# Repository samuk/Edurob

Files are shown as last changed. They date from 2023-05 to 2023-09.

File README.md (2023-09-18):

# EduRob
[Homepage](https://www.imsl.fh-dortmund.de/mobile-roboter/edurob/)
## Educational robot with support for various drive kinematics

EduRob is a handy mobile robot specially designed for education. Through clever design, it is possible to cover different types of drives such as Mecanum, Omniwheel, and differential drive.



## Detailed information:

[Getting Started](Doc/README.md)

[Partslist](Doc/Partslist/README.md)

[PCB](PCB/README.md) 

[CAD](CAD/README.md) 

## Example projects:

[SLAM](Projects/SLAM/README.md)

[Line Follower](https://github.com/blssed/EduRob-LineFollower)

---

## Background

In the robotics lab, there is a wide range of different robots available for use in teaching and for the completion of thesis projects. However, they all share one major disadvantage: they prefer to drive themselves rather than being carried. As a result, their application is limited to the lab itself and adjacent rooms.

Especially for basic training in mobile robotics such as controlling different types of drives (Mecanum, Omniwheel, or differential drive), implementing control tasks, and connecting sensors, the experimental area of the robotics lab is not necessarily required. This led to the requirement of developing a flexible platform that can cover all types of drives, and small enough to be taken in a backpack to the home office.

# Possible configurations

EduRob can be equipped with three or four motors and different types of wheels. The motors can be flexibly reconnected by loosening two screws, and other wheels can be attached to the motor shaft.

## Mecanum 

With four motors at the four outer corners, EduRob can be turned into a robot with a classic Mecanum drive. The driving behavior is thus similar to that of OmniMan and the other Mecanum robots of the IMSL.



## Omniwheel with three wheels (120°)

With three motors, EduRob can simulate the classic omniwheel configuration. Three wheels rotated by 120° each allow for omnidirectional driving behavior.



## Omniwheel with four wheels (90°)

In addition to the classic arrangement with three omniwheels, EduRob can also simulate the special form with four omniwheels. Here, four omniwheels are arranged with a rotation of 90° to each other. In comparison to the Mecanum arrangement, the wheels are rotated by about 45°. In this configuration, EduRob can also be driven omnidirectionally.



## Differential drive or Skid-Steer drive

The driving behavior of the Pioneer robots in the IMSL inventory is made possible by the use of four wheels. Even though the arrangement of the wheels is similar to the Mecanum arrangement, sideways movement is not possible due to the use of classic wheels without freewheeling rollers. In addition to forward and backward movement and rotation around the center of the platform, driving in circular arcs is possible. This type of drive is also called Skid-Steer drive. Due to the 4x4 drive, this configuration is particularly suitable for rough terrain. The absence of freewheeling rollers on the wheels also means they are less likely to become contaminated or blocked.



By using two classic wheels and one or two non-driven Omniwheels, a proper differential drive is also possible. In this case, the rotation point moves to the midpoint between the two driven wheels. While this affects the robot's turning behavior (the front part swings out), it still maintains its limited range of movement (forward, backward, turning, and driving in circles). However, the "off-road" capability is reduced by the reduction to two driven wheels, and the use of Omniwheels increases the risk of contamination of free-rolling rollers.



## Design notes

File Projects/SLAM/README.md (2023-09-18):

# EduRob SLAM
[Homepage](https://www.imsl.fh-dortmund.de/mobile-roboter/edurob/)
## Project files for SLAM with EduRob

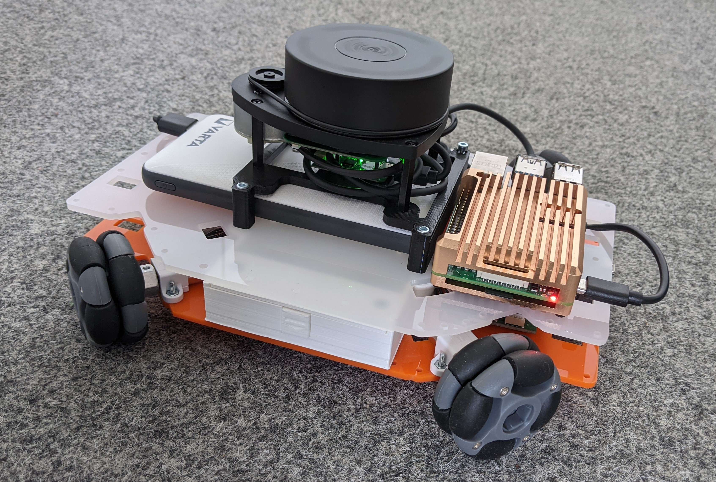
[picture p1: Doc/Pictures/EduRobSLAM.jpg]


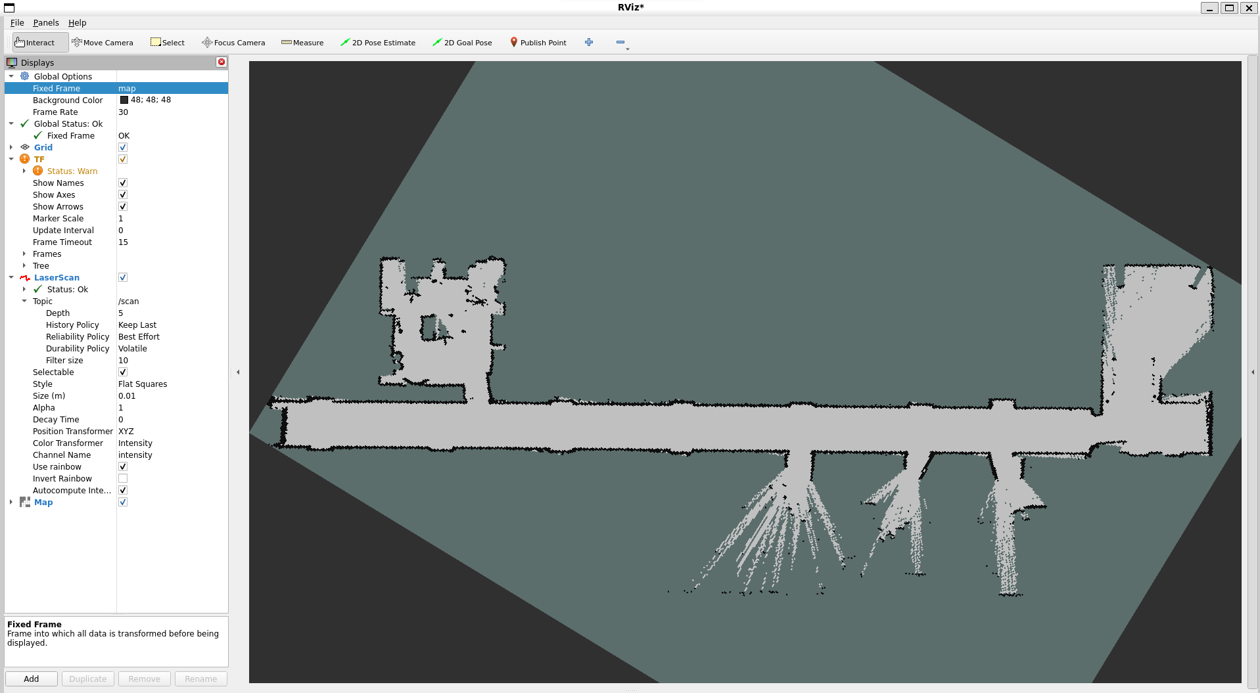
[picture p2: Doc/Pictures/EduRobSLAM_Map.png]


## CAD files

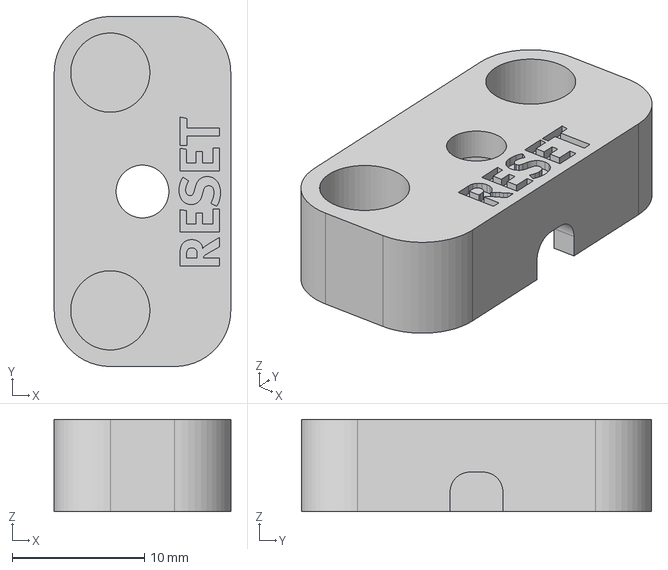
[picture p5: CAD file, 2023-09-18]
CAD/EduRob_Reset_Button_Holder.step
13.4 x 26.5 x 7.00 mm

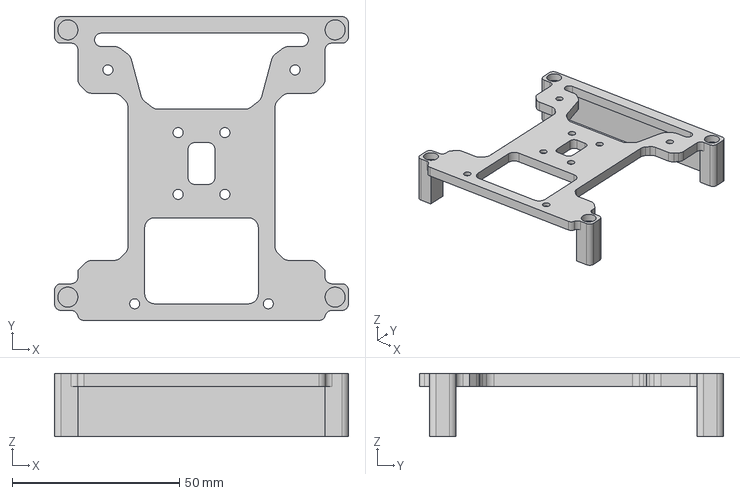
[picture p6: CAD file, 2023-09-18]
Projects/SLAM/LIDAR_Adapter v5.step
88.0 x 91.0 x 19.0 mm

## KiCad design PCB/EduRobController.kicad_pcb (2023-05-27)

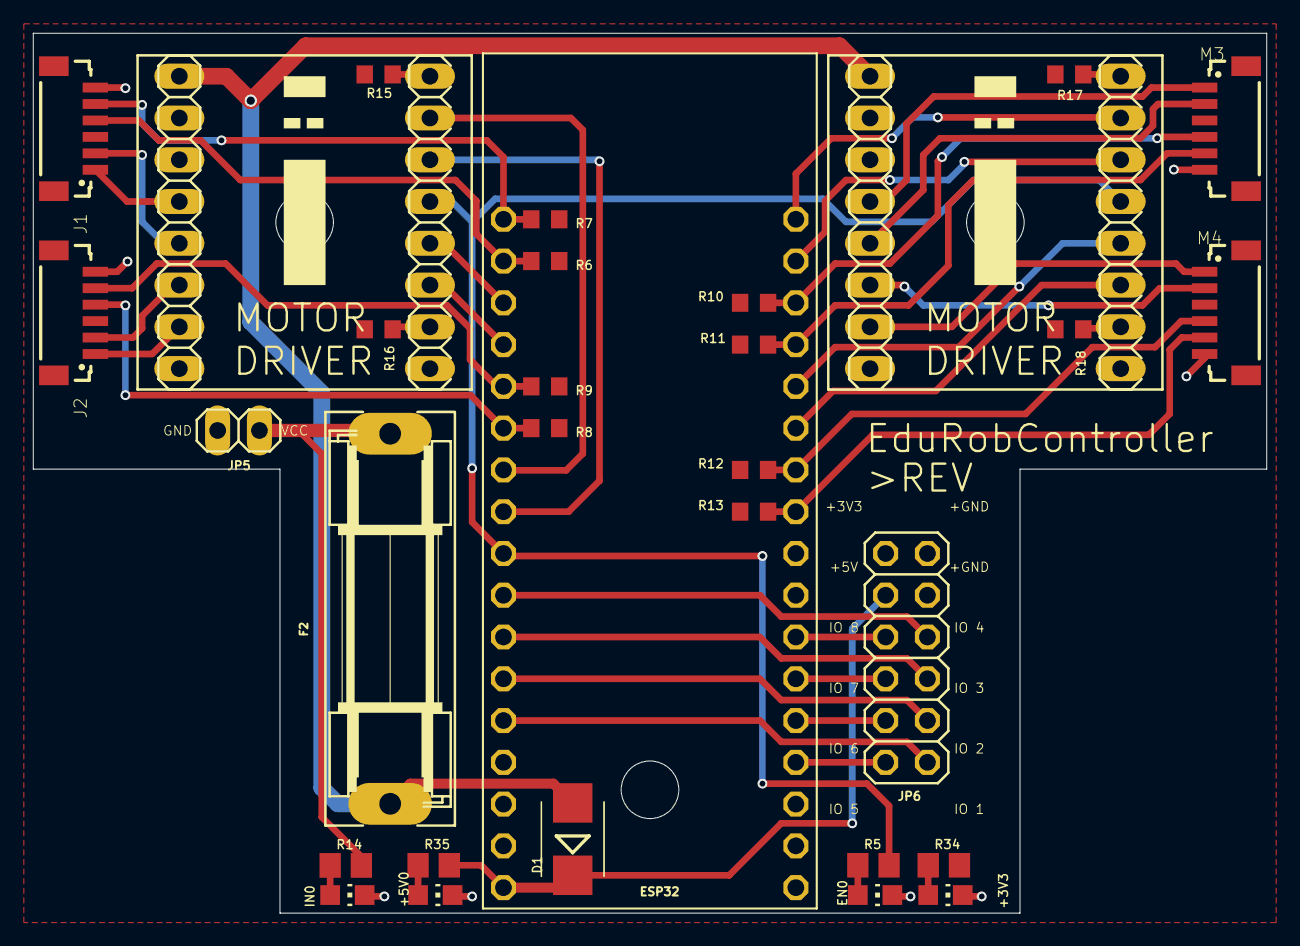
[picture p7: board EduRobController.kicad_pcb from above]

Board: 2 copper layers, 75.0 x 53.5 mm, 34 parts (0 on the bottom side), 46 nets.

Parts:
+3V3, +5V0: CHIP-LED0805
@HOLE0, @HOLE1, @HOLE2: (no value)
D1: SMB
EN0: CHIP-LED0805
F2: 534-4628; SH22,5
IN0: CHIP-LED0805
J1, J2: 665306124022
JP5: 1X02
JP6: 2X06
M3, M4: 665306124022
R5, R14, R34, R35: R0805
R6, R7, R8, R9, R10, R11, R12, R13, R15, R16, R17, R18: R0603
U$1: ESP32
U$2, U$3: TB6612FNG; 2X08

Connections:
+3V3: J1.3, J2.3, JP6.12, M3.3, M4.3, R6.2, R7.2, R8.2, R9.2, R10.2, R11.2, R12.2, R13.2, R15.2, R16.2, R17.2, R18.2, R34.2, U$1.3V3, U$1.3V3., U$2.7, U$3.7
+5V: D1.C, JP6.10, R35.2, U$1.5V
ENM: R5.2, U$1.12, U$2.13, U$3.13
GND: +3V3.C, +5V0.C, EN0.C, IN0.C, J1.6, J2.6, JP5.2, JP6.9, JP6.11, M3.6, M4.6, U$1.GND, U$1.GND., U$2.1, U$2.6, U$2.9, U$3.1, U$3.6, U$3.9
GPIO1: JP6.1, U$1.4
GPIO2: JP6.3, U$1.2
GPIO3: JP6.5, U$1.15
GPIO4: JP6.7, U$1.13
GPIO5: JP6.2, U$1.37
GPIO6: JP6.4, U$1.38
GPIO7: JP6.6, U$1.34
GPIO8: JP6.8, U$1.35
M1A: J1.1, U$2.5
M1B: J1.2, U$2.4
M1ENCA: J1.4, R6.1, U$1.VN
M1ENCB: J1.5, R7.1, U$1.VP
M1PWMA: U$1.14, U$2.14
M1PWMB: U$1.27, U$2.15
M2A: J2.1, U$2.2
M2B: J2.2, U$2.3
M2ENCA: J2.4, R8.1, U$1.33
M2ENCB: J2.5, R9.1, U$1.32
M2PWMA: U$1.25, U$2.12
M2PWMB: U$1.26, U$2.11
M3A: M3.1, U$3.5
M3B: M3.2, U$3.4
M3ENCA: M3.4, R10.1, U$1.19
M3ENCB: M3.5, R11.1, U$1.23
M3PWMA: U$1.22, U$3.14
M3PWMB: U$1.21, U$3.15
M4A: M4.1, U$3.2
M4B: M4.2, U$3.3
M4ENCA: M4.4, R12.1, U$1.10
M4ENCB: M4.5, R13.1, U$1.9
M4PWMA: U$1.18, U$3.12
M4PWMB: U$1.5, U$3.11
unnamed: +3V3.A, R34.1
unnamed: +5V0.A, R35.1
unnamed: EN0.A, R5.1
unnamed: IN0.A, R14.1
unnamed: R17.1, U$3.16
unnamed: R18.1, U$3.10
unnamed: R15.1, U$2.16
unnamed: R16.1, U$2.10
VCC: F2.1, JP5.1, R14.2
VDD: D1.A, F2.2, U$2.8, U$3.8

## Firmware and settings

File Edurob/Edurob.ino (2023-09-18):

#define ROS_EN
// #define ROS_CON_WIFI // Use WIFI instead of Serial (USB)

// #define MECANUM
// #define DIFF
#define OMNI4
// #define OMNI3

#ifdef ROS_EN
#define RCCHECK(fn)              \
  {                              \
    rcl_ret_t temp_rc = fn;      \
    if ((temp_rc != RCL_RET_OK)) \
    {                            \
      error_loop();              \
    }                            \
  }
#define RCSOFTCHECK(fn)          \
  {                              \
    rcl_ret_t temp_rc = fn;      \
    if ((temp_rc != RCL_RET_OK)) \
    {                            \
    }                            \
  }
#endif // ROS_EN

#include <WiFi.h>
#include "sdkconfig.h"
#include "esp_system.h"
#include "freertos/FreeRTOS.h"
#include "freertos/task.h"
#include "freertos/timers.h"
#include "freertos/event_groups.h"
#include "math.h"

#include <dcpwm.h>       // PWM
#include <ESP_Counter.h> // Encoder
#include <AutoPID.h>     // PID Library https://github.com/r-downing/AutoPID
#include <Eigen.h>       // Linear math
#include <Eigen/QR>      // Calls inverse, determinant, LU decomp., etc.
using namespace Eigen;   // Eigen related statement; simplifies syntax for declaration of matrices

#ifdef ROS_EN
// ROS
#include <micro_ros_arduino.h>
#include <stdio.h>
#include <rcl/rcl.h>
#include <rcl/error_handling.h>
#include <rclc/rclc.h>
#include <rclc/executor.h>
#include <micro_ros_utilities/type_utilities.h>
#include <micro_ros_utilities/string_utilities.h>

// ROS Messages
#include <geometry_msgs/msg/twist.h>
#include <geometry_msgs/msg/transform_stamped.h>
#include <tf2_msgs/msg/tf_message.h>
#include <custom_message/msg/speed.h>
#endif ROS_EN

// Project specific headers
#include "parameter.h"

// Hardware
static ESP_Counter WheelEncoder[NumMotors];      // Hardware-Encoder-Units
static DCPWM MotorPWM[NumMotors];                // Hardware-PWM-Units
static AutoPID *speedController[NumMotors];      // PID-Units
static pidParam speedControllerParam[NumMotors]; // PID-Parameter

// Variables
int64_t encoderOld[NumMotors];       // Last encoder values
int64_t encoderNew[NumMotors];       // Current encoder values
const int windowSize = 5;            // Number of values in moving average window
float inputs[NumMotors][windowSize]; // Input values for moving average
float inputsum[NumMotors];           // Sum of values for moving average
int windowIndex = 0;                 // Currently accessed cell of inputs[motornum][x];

// Setpoints
static double setpointSpeed[NumMotors]; // Motorspeed setpoints

// Matrix
MatrixXd kinematik(4, 3);    // Kinematics matrix for differential
MatrixXd kinematikInv(3, 4); // Inverse Kinematics matrix for differential
Vector3d robotSpeedSetpoint; // Vector with translationional and rotational robot speeds in m/s and rad/s  (X(m/s), Y(m/s), Z(rad/s))
Vector3d robotSpeed;         // Vector with translationional and rotational robot speeds in m/s and rad/s  (X(m/s), Y(m/s), Z(rad/s))
Vector3d robotSpeedMax;      // Vector with translationional and rotational robot speeds in m/s and rad/s  (X(m/s), Y(m/s), Z(rad/s))
Vector3d robotSpeedAcc;      // Vector with translationional and rotational robot speeds in m/s and rad/s  (X(m/s), Y(m/s), Z(rad/s))
Vector4d wheelSpeedSetpoint; // Wheel speeds in rad/s
Vector3d robotOdom;          // Odometry Position
Vector4d robotWheelSpeed;    // Current wheel speeds
Vector3d robotOdomSpeed;     // Odometry Speed
double rosQuaternion[4];     // Quaternion for ROS transform message

#ifdef ROS_EN
// ROS
rclc_support_t support;
rcl_allocator_t allocator;
rclc_executor_t executor;
rcl_node_t node;

geometry_msgs__msg__TransformStamped tfData[3];
geometry_msgs__msg__TransformStamped tfStaticData[3];
int32_t speedData[4];
rcl_subscription_t twistSubscriber;
geometry_msgs__msg__Twist twistMessage;

tf2_msgs__msg__TFMessage messageTf;
rcl_publisher_t publisherTf;
tf2_msgs__msg__TFMessage messageTfStatic;
rcl_publisher_t publisherTfStatic;
custom_message__msg__Speed messageSpeed;
rcl_publisher_t publisherSpeed;
#endif // ROS_EN

// Error function in case of unhandeld ros-error
void error_loop()
{
  while (1)
  {
    Serial.println("ERR");
    delay(100);
  }
}

// Convert Eulerdegrees to quaternion
const void euler_to_quat(float x, float y, float z, double *q)
{
  float c1 = cos(y / 2.0);
  float c2 = cos(z / 2.0);
  float c3 = cos(x / 2.0);

  float s1 = sin(y / 2.0);
  float s2 = sin(z / 2.0);
  float s3 = sin(x / 2.0);

  q[0] = c1 * c2 * c3 - s1 * s2 * s3;
  q[1] = s1 * s2 * c3 + c1 * c2 * s3;
  q[2] = s1 * c2 * c3 + c1 * s2 * s3;
  q[3] = c1 * s2 * c3 - s1 * c2 * s3;
}

// Rotate 2D-Vector
const void rotate2D(float r, double &x, double &y)
{
  double temp = x * cos(r) - y * sin(r);
  y = x * sin(r) + y * cos(r);
  x = temp;
}

// Twist message cb
void subscription_callback(const void *msgin)
{
  const geometry_msgs__msg__Twist *msga = (const geometry_msgs__msg__Twist *)msgin;
  robotSpeedSetpoint << msga->linear.x, msga->linear.y, msga->angular.z;
}

// Print content of Eigen::MatrixXd
void print_mtxd(const Eigen::MatrixXd &X)
{
  int i, j, nrow, ncol;

  nrow = X.rows();
  ncol = X.cols();

  Serial.print("nrow: ");
  Serial.println(nrow);
  Serial.print("ncol: ");
  Serial.println(ncol);
  Serial.println();

  for (i = 0; i < nrow; i++)
  {
    for (j = 0; j < ncol; j++)
    {
      Serial.print(X(i, j), 6); // print 6 decimal places
      Serial.print(", ");
    }
    Serial.println();
  }
  Serial.println();
}

// Init Encoder- and PWM-Units
bool initHardware()
{
  pinMode(EnablePIN, OUTPUT);   // Motor enable signal
  digitalWrite(EnablePIN, LOW); // Disable motors
  for (int i = 0; i < NumMotors; i++)
  {
    if (!WheelEncoder[i].init(i, Enc_A[i], Enc_B[i]))
    {
      return false;
    }
  }

  int currentChannel = 0;
  for (int i = 0; i < NumMotors; i++)
  {
    if (!MotorPWM[i].init(30000, 10, currentChannel, currentChannel + 1, PWM_A[i], PWM_B[i]))
    {
      return false;
    }
    MotorPWM[i].setPWM(0); // Set initial speed to 0
    currentChannel += 2;
  }

  return true;
}

// Init speed controller
void initPID()
{
  for (int i = 0; i < NumMotors; i++)
  {
    speedControllerParam[i].input = 0;
    speedControllerParam[i].output = 0;
    speedControllerParam[i].setpoint = 0;
    speedControllerParam[i].p = 0.04;
    speedControllerParam[i].i = 0.08;
    speedControllerParam[i].d = 0.0;
    speedControllerParam[i].sampleTimeMs = sampleTime;
    speedControllerParam[i].outMin = -100;
    speedControllerParam[i].outMax = 100;

    speedController[i] = new AutoPID(&speedControllerParam[i].input, &speedControllerParam[i].setpoint, &speedControllerParam[i].output, speedControllerParam[i].outMin, speedControllerParam[i].outMax, speedControllerParam[i].p, speedControllerParam[i].i, speedControllerParam[i].d);
    speedController[i]->setTimeStep(speedControllerParam[i].sampleTimeMs);
    speedController[i]->setBangBang(0, 0); // Disable BangBang-Controll
  }
}

// Init platformspecific kinematics
void initMatrix()
{

#ifdef MECANUM
  // Mecanum
  kinematik << 1, 1, (l1 + l2),
      1, -1, -(l1 + l2),
      1, -1, (l1 + l2),
      1, 1, -(l1 + l2);

  kinematikInv << 1, 1, 1, 1,
      1, -1, 1, -1,
      1.0 / (l1 + l2), -1.0 / (l1 + l2), 1.0 / (l1 + l2), -1.0 / (l1 + l2);

  kinematik = 1 * kinematik;
  kinematikInv = (1 / 4.0) * kinematikInv;
#endif

#ifdef DIFF
  // Diff
  kinematik << 1, 0, l2,
      1, 0, -l2,
      1, 0, l2,
      1, 0, -l2;

  kinematikInv << 1, 1, 1, 1,
      0, 0, 0, 0,
      1.0 / l2, -1.0 / l2, 1.0 / l2, -1.0 / l2;

  kinematik = 1 * kinematik;
  kinematikInv = (1 / 4.0) * kinematikInv;
#endif

#ifdef OMNI4
  // Omni 4 Wheels
  kinematik << -(1), -(1), (sqrt(2) * 0.08305),
      -(1), (1), -(sqrt(2) * 0.08305),
      -(1), (1), (sqrt(2) * 0.08305),
      -(1), -(1), -(sqrt(2) * 0.08305);

  kinematikInv << -sqrt(2) / 2, -sqrt(2) / 2, -sqrt(2) / 2, -sqrt(2) / 2,
      -sqrt(2) / 2, sqrt(2) / 2, sqrt(2) / 2, -sqrt(2) / 2,
      1 / (2 * (sqrt(2) * 0.08305)), -1 / (2 * (sqrt(2) * 0.08305)), 1 / (2 * (sqrt(2) * 0.08305)), -1 / (2 * (sqrt(2) * 0.08305));

  kinematik = ((sqrt(2) / (2))) * kinematik;
  kinematikInv = (0.5) * kinematikInv;
#endif

  robotSpeedSetpoint << 0.0,
      0.0,
      0.0;

  robotSpeedAcc << maxTAccel, maxTAccel, maxRAccel;
  robotSpeedMax << maxTSpeed, maxTSpeed, maxRSpeed;
  wheelSpeedSetpoint = (1 / wheelRadius) * kinematik * robotSpeedSetpoint;
}

// Speed controller task
void speedControllerTask(void *pvParameters)
{
  TickType_t xLastWakeTime = xTaskGetTickCount();
  const TickType_t xFrequency = pdMS_TO_TICKS(sampleTime);

  for (int i = 0; i < NumMotors; i++)
  {
    inputsum[i] = 0;
  }

  for (int i = 0; i < NumMotors; i++)
  {
    for (int k = 0; k < windowSize; k++)
    {
      inputs[i][k] = 0;
    }
  }

  while (true)
  {
    vTaskDelayUntil(&xLastWakeTime, xFrequency);
    for (int i = 0; i < 3; i++)
    {
      if (robotSpeed[i] > robotSpeedSetpoint[i])
      {
        robotSpeed[i] = robotSpeed[i] - (robotSpeedAcc[i] * 0.005);
      }
      else if (robotSpeed[i] < robotSpeedSetpoint[i])
      {
        robotSpeed[i] = robotSpeed[i] + (robotSpeedAcc[i] * 0.005);
      }

      if (robotSpeed[i] > robotSpeedMax[i])
      {
        robotSpeed[i] = robotSpeedMax[i];
      }
      else if (robotSpeed[i] < -robotSpeedMax[i])
      {
        robotSpeed[i] = -robotSpeedMax[i];
      }
    }
    wheelSpeedSetpoint = (1 / wheelRadius) * kinematik * robotSpeed;
    for (int i = 0; i < NumMotors; i++)
    {
      if (abs(wheelSpeedSetpoint[i]) < 0.15)
      {
        wheelSpeedSetpoint[i] = 0;
      }
    }

    for (int i = 0; i < NumMotors; i++)
    {
      speedControllerParam[i].setpoint = wheelSpeedSetpoint(i, 0);
      encoderNew[i] = EncoderDir[i] * WheelEncoder[i].getCount();

      inputsum[i] -= inputs[i][windowIndex];
      inputs[i][windowIndex] = ((((encoderNew[i] - encoderOld[i]) * incrementsToRad) / sampleTime) * 1000);
      inputsum[i] += inputs[i][windowIndex];

      speedControllerParam[i].input = inputsum[i] / windowSize; // Filtered

      speedController[i]->run();

      MotorPWM[i].setPWM(MotorDir[i] * speedControllerParam[i].output * Rad2PWM); // Raw
      encoderOld[i] = encoderNew[i];
    }
    for (int i = 0; i < NumMotors; i++)
    {
      robotWheelSpeed[i] = inputs[i][windowIndex];
    }
    robotOdomSpeed = (wheelRadius * kinematikInv * robotWheelSpeed);
    rotate2D(robotOdom[2], robotOdomSpeed[0], robotOdomSpeed[1]);
    robotOdom[0] = robotOdomSpeed[0] / 200 + robotOdom[0];
    robotOdom[1] = robotOdomSpeed[1] / 200 + robotOdom[1];
    robotOdom[2] = robotOdomSpeed[2] / 200 + robotOdom[2];
    windowIndex = (windowIndex + 1) % windowSize;
  }
}

// Logger task
void loggerTask(void *pvParameters)
{
  while (true)
  {
    vTaskDelay(pdMS_TO_TICKS(5));
    //   Serial.print("Odometry: Xt= ");
    //   Serial.print(robotOdom[0]);  //current x-position in meters
    //   Serial.print(", Yt= ");
    //   Serial.print(robotOdom[1]);  //current y-position in meters
    //   Serial.print(", Zr= ");
    //   Serial.println(robotOdom[2]);  //current z-rotation in radians
  }
}

// Set tf data
void setTfData()
{
  tfData[0].header.frame_id =
      micro_ros_string_utilities_set(tfData[0].header.frame_id, "/odom");
  tfData[0].child_frame_id =
      micro_ros_string_utilities_set(tfData[0].child_frame_id, "/base_link");
  tfData[0].transform.translation.x = robotOdom[0];
  tfData[0].transform.translation.y = robotOdom[1];
  euler_to_quat(0, 0, robotOdom[2], rosQuaternion);
  tfData[0].transform.rotation.x = (double)rosQuaternion[1];
  tfData[0].transform.rotation.y = (double)rosQuaternion[2];
  tfData[0].transform.rotation.z = (double)rosQuaternion[3];
  tfData[0].transform.rotation.w = (double)rosQuaternion[0];
  tfData[0].header.stamp.nanosec = rmw_uros_epoch_millis() * 1000;
  tfData[0].header.stamp.sec = rmw_uros_epoch_millis() / 1000;

  messageTf.transforms.size = 1;
  messageTf.transforms.data = tfData;
}

// Set static tf data
void setTfStaticData()
{
  tfStaticData[0].header.frame_id =
      micro_ros_string_utilities_set(tfStaticData[0].header.frame_id, "/base_link");
  tfStaticData[0].child_frame_id =
      micro_ros_string_utilities_set(tfStaticData[0].child_frame_id, "/laser_link");
  tfStaticData[0].transform.translation.x = 0;
  tfStaticData[0].transform.translation.y = 0;
  tfStaticData[0].transform.translation.z = 0.08;
  tfStaticData[0].transform.rotation.x = 0;
  tfStaticData[0].transform.rotation.y = 0;
  tfStaticData[0].transform.rotation.z = 0;
  tfStaticData[0].transform.rotation.w = 1;
  tfStaticData[0].header.stamp.nanosec = rmw_uros_epoch_millis() * 1000;
  tfStaticData[0].header.stamp.sec = rmw_uros_epoch_millis() / 1000;

  messageTfStatic.transforms.size = 1;
  messageTfStatic.transforms.data = tfStaticData;
}

// Setup
void setup()
{
  Serial.begin(115200);
  initHardware();
  initPID();
  initMatrix();

  xTaskCreate(
      speedControllerTask,   /* Task function. */
      "speedControllerTask", /* String with name of task. */
      100000,                /* Stack size in bytes. */
      NULL,                  /* Parameter passed as input of the task */
      5,                     /* Priority of the task. */
      NULL);                 /* Task handle. */
  xTaskCreate(
      loggerTask,   /* Task function. */
      "loggerTask", /* String with name of task. */
      20000,        /* Stack size in bytes. */
      NULL,         /* Parameter passed as input of the task */
      1,            /* Priority of the task. */
      NULL);        /* Task handle. */

#ifdef ROS_EN
#ifdef ROS_CON_WIFI
  Serial.println("Connecting via Wifi...");
  // set_microros_wifi_transports("imslhotspot", "imslhotspotwifikey", "10.0.103.67", 8888);

  set_microros_wifi_transports("ESPNET", "espnetwifikey", "10.0.103.67", 8888);
  Serial.print("Connected via Wifi (IP: ");
  Serial.print(WiFi.localIP());
  Serial.println(")");
  delay(2000);
#endif // ROS_CON_WIFI
#ifndef ROS_CON_WIFI
  set_microros_transports();
#endif // ROS_CON_WIFI

  allocator = rcl_get_default_allocator();
  // create init_options
  RCCHECK(rclc_support_init(&support, 0, NULL, &allocator));
  // create node
  RCCHECK(rclc_node_init_default(&node, "Edurob", "", &support));
  // create tf publisher
  RCCHECK(rclc_publisher_init_default(
      &publisherTf,
      &node,
      ROSIDL_GET_MSG_TYPE_SUPPORT(tf2_msgs, msg, TFMessage),
      "/tf"));

  // create tf publisher
  // Set publisher QoS

  rmw_qos_profile_t rmw_qos_profile_tfstatic = {RMW_QOS_POLICY_HISTORY_KEEP_LAST, 10U, RMW_QOS_POLICY_RELIABILITY_RELIABLE, RMW_QOS_POLICY_DURABILITY_TRANSIENT_LOCAL, {0ULL, 0ULL}, {0ULL, 0ULL}, RMW_QOS_POLICY_LIVELINESS_SYSTEM_DEFAULT, {0ULL, 0ULL}, false};

  RCCHECK(rclc_publisher_init(
      &publisherTfStatic,
      &node,
      ROSIDL_GET_MSG_TYPE_SUPPORT(tf2_msgs, msg, TFMessage),
      "/tf_static",
      &rmw_qos_profile_tfstatic));

  // create speed publisher
  RCCHECK(rclc_publisher_init_default(
      &publisherSpeed,
      &node,
      ROSIDL_GET_MSG_TYPE_SUPPORT(custom_message, msg, Speed),
      "/fixposition/speed"));

  // create subscriber
  RCCHECK(rclc_subscription_init_default(
      &twistSubscriber,
      &node,
      ROSIDL_GET_MSG_TYPE_SUPPORT(geometry_msgs, msg, Twist),
      "cmd_vel"));

  // create executor
  RCCHECK(rclc_executor_init(&executor, &support.context, 1, &allocator));
  RCCHECK(rclc_executor_add_subscription(&executor, &twistSubscriber, &twistMessage, &subscription_callback, ON_NEW_DATA));

#endif // ROS_EN
}

void loop()
{
  digitalWrite(EnablePIN, HIGH); // Enable motors

  // #############-USER-CODE-START-#####################
  // double tx = 0.0, ty = 0.0, theta = 0.0;
  // robotSpeedSetpoint << tx, ty, theta;

  // #############-USER-CODE-END-#####################

#ifdef ROS_EN

  rmw_uros_sync_session(100); // Synchronize time

  if (rmw_uros_epoch_synchronized())
  {

    speedData[0] = sqrt(robotOdomSpeed[0] * robotOdomSpeed[0] + robotOdomSpeed[1] * robotOdomSpeed[1]) * 1000; // Current Speed in mm/s
    speedData[1] = robotOdomSpeed[2] * 1000;                                                                   // Current rotational speed in mrad/s
    messageSpeed.speeds.capacity = 2;
    messageSpeed.speeds.data = speedData;
    messageSpeed.speeds.size = 2;
    setTfData();
    setTfStaticData();
    RCSOFTCHECK(rcl_publish(&publisherTf, &messageTf, NULL));
    RCSOFTCHECK(rcl_publish(&publisherTf, &messageTfStatic, NULL));
    RCSOFTCHECK(rcl_publish(&publisherSpeed, &messageSpeed, NULL));
  }

  RCCHECK(rclc_executor_spin_some(&executor, 0));
#endif // ROS_EN
  delay(10);
}

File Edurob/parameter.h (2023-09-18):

#ifndef PARAMETER_H
#define PARAMETER_H

// Parameters

// #############-USER-CODE-START-#####################
static const double wheelRadius = 0.024;       // Wheelradius in meters
static const double l1 = 0.212 / 2;            // Distance between axels aka "length"
static const double l2 = 0.135 / 2;            // Distance between wheels aka "width"
static const float maxTSpeed = 0.5;            // Maximum translational speed in m/s
static const float maxRSpeed = 1.5;            // Maximum rotational speed in rad/s
static const float maxTAccel = 0.5;            // Maximum translational acceleration in m/s²
static const float maxRAccel = 1.5;            // Maximum rotational acceleration in rad/s²
static const int EncoderDir[4] = {1, 1, 1, 1}; // Counting direction of encoderchannels (+1 or -1)
static const int MotorDir[4] = {1, 1, 1, 1};   // Direction of motors (+1 or -1)
// #############-USER-CODE-END-#####################

static const int NumMotors = 4;                                          // Number of Motors (Max=4)
static const int sampleTime = 5;                                         // Sample time in ms
static const int gearing = 150.0;                                        // Number of motorrotations per wheelrotation
static const int encoderSteps = 12;                                      // Number of encoder increments per motorrotation
static const double incrementsToRad = 2 * PI / (encoderSteps * gearing); // Conversion from encoder increments to rad
static const double circumference = (2 * PI * wheelRadius);              // Circumference in meters
static const double msToRads = (2 * PI) / circumference;                 // Conversion from m/s to rad/s
static const int nMax = 210;                                             // Maximum revolutions / min
static double Rad2PWM = 100.0 * 60.0 * gearing / (2.0 * PI * nMax);      // Conversion from rad/s to pwm duty cicle

// Motornumbering
// |2|--|1|
//    ||
// |3|--|4|

// Pin definitions
static const int PWM_A[4] = {25, 5, 14, 21};  // GPIO PWM channel A
static const int PWM_B[4] = {26, 18, 27, 22}; // GPIO PWM channel B
static const int Enc_A[4] = {32, 10, 36, 19}; // GPIO Encoder channel A
static const int Enc_B[4] = {33, 9, 39, 23};  // GPIO Encoder channel B
static const int EnablePIN = 12;              // Enable Signalpin for motordrivers

typedef struct pidParam
{                   // PID Parameters
  double input;     // Input data
  double output;    // Output data
  double setpoint;  // Setpoint
  double p;         // Proportional
  double i;         // Integral
  double d;         // Differential
  int sampleTimeMs; // Sampletime in ms
  double outMin;    // Lower limit of output
  double outMax;    // Upper limit of output
};

#endif // PARAMETER_H

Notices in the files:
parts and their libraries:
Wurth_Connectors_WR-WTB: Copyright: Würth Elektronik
